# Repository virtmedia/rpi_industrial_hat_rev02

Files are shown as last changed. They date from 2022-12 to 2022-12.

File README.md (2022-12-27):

# rpi_industrial_hat_rev02
Raspberry Pi hat with industrial-style 2xDI+2xDQ+1W

## Features:
- power supply input 10-26 V with fuse protection, overvoltage protection and reverse polarity protection
- possible to set low voltage level eg. to protect 12V baterry from draining.
- 2 relays for outputs (both NO and NC contacts accesible)
- 2 optocouplers for inputs (can be used SMD or THT versions in 4-pin package)
- 3-pin connector for 1-Wire devices (eg. D18B20 thermometers)
- terminal blocks connectors
- UART conenctor
- I2C connector
- Domoticz and Home Assistant friendly

## Signals used from Raspberry Pi GPIO connector:
- GPIO04: 1-wire
- GPIO17: Relay #2
- GPIO18: Relay #1
- GPIO22: Input #1
- GPIO27: Input #2

Photo of the board (revision 01 with some small mistake, corrected in current revision):
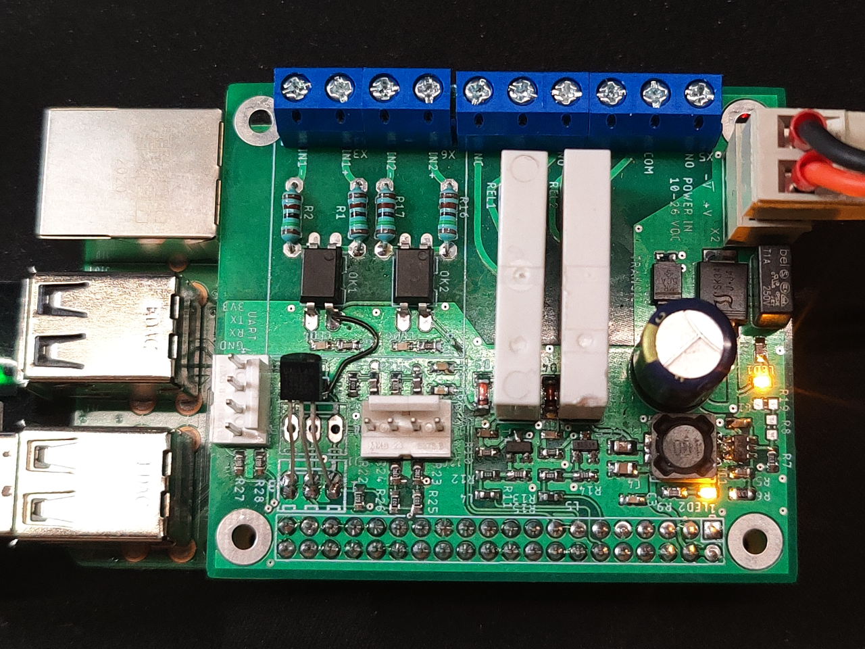
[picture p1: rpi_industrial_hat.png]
PCB photo


I've included:
- Schematic in PDF
- Board visualisation in PDF
- Gerber files in .zip ready to be send to PCB manufacturer
- Eagle files

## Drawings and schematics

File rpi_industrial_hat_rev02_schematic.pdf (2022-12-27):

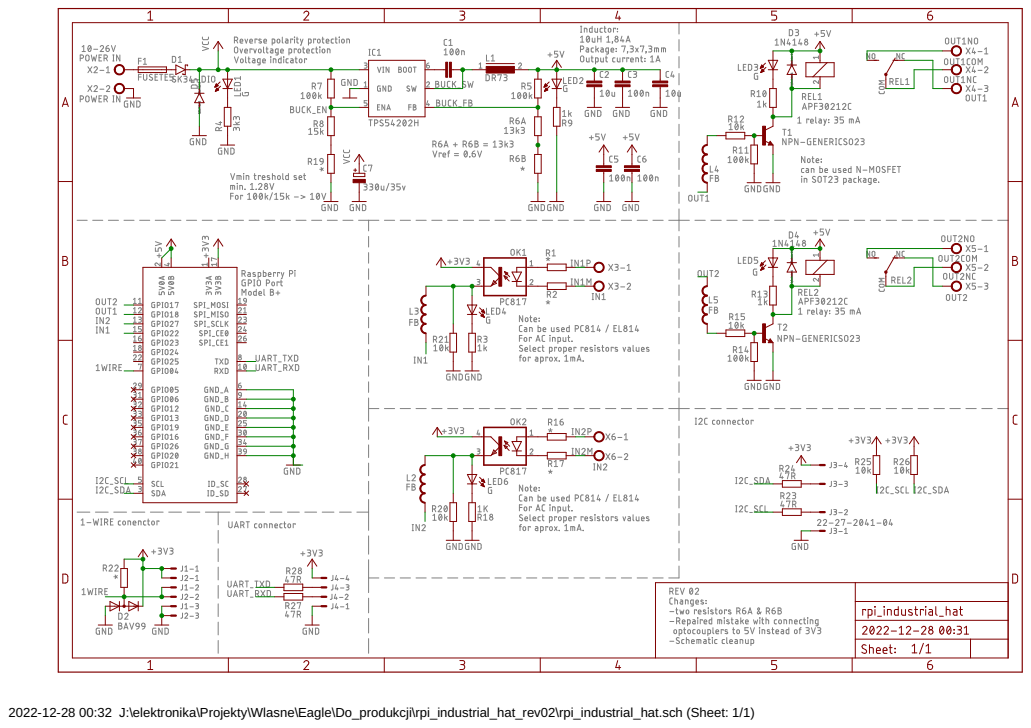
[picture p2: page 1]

2022-12-28 00:32 J:\elektronika\Projekty\Wlasne\Eagle\Do_produkcji\rpi_industrial_hat_rev02\rpi_industrial_hat.sch (Sheet: 1/1)

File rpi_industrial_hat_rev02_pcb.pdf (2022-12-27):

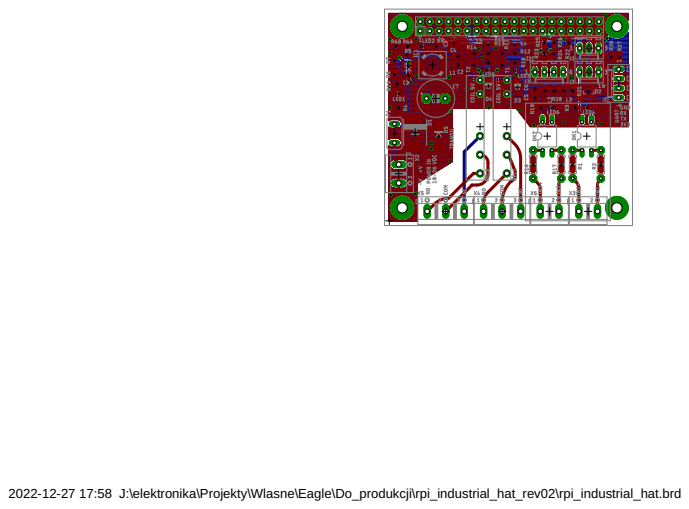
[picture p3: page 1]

2022-12-27 17:58 J:\elektronika\Projekty\Wlasne\Eagle\Do_produkcji\rpi_industrial_hat_rev02\rpi_industrial_hat.brd

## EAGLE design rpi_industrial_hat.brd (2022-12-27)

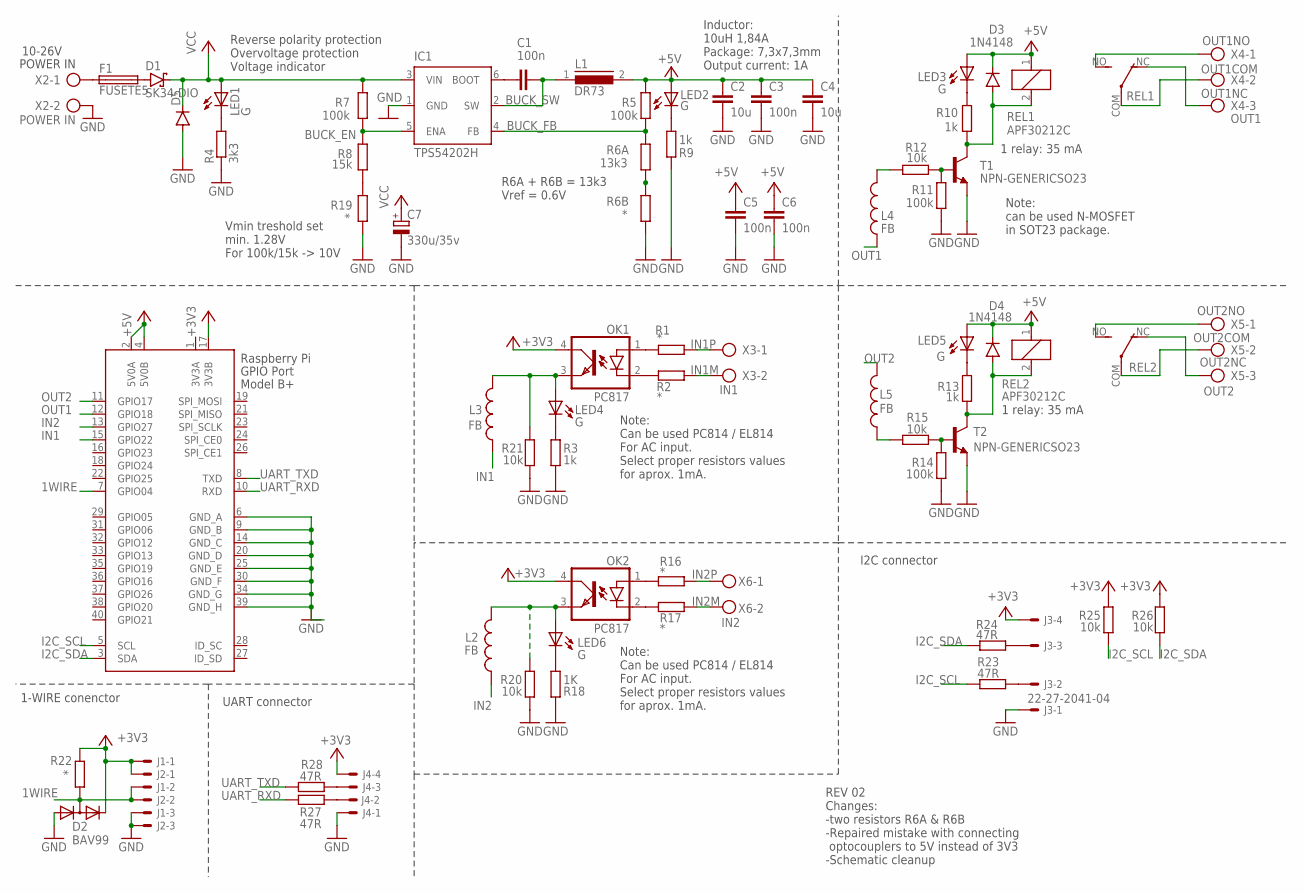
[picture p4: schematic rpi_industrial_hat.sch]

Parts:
C1, C3, C5, C6: 100n; C0603
C2, C4: 10u; C0805
C7: 330u/35v; E5-10,5
D1: SK34-DIO; SMC
D2: BAV99; SOT23
D3, D4: 1N4148; MINIMELF
D5: DIODE-DO214AA; DO214AA
F1: FUSETE5; TE5
IC1: TPS54202H; SOT23-6
J1, J2: 22-27-2031-03; 6410-03
J3, J4: 22-27-2041-04; 6410-04
L1: DR73
L2, L3, L4, L5: FB; 0603
LED1, LED2, LED3, LED4, LED5, LED6: G; CHIP-LED0603
OK1, OK2: PC817; DIL04
R1, R2, R16, R17: *; 0204/7/SMD
R3, R9, R10, R13: 1k; R0603
R4: 3k3; R0603
R5, R7, R11, R14: 100k; R0603
R6A: 13k3; R0603
R6B, R19, R22: *; R0603
R8: 15k; R0603
R12, R15, R20, R21, R25, R26: 10k; R0603
R18: 1K; R0603
R23, R24, R27, R28: 47R; R0603
REL1, REL2: APF30212C
T1, T2: NPN-GENERICSO23; SOT23
X1: RASPI_BOARD_B+#_E4P; RASPI_BOARD_B+_EDGES_4DRILL_PAD
X2: POWER IN; AK500/2
X3: IN1; AK500/2
X4: OUT1; AK500/3
X5: OUT2; AK500/3
X6: IN2; AK500/2

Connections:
1WIRE: D2.3 (K1A2), J1.2, J2.2, R22.1, X1.7 (GPIO04)
3V3A: X1.1 (3V3A)
+3V3: D2.2 (K2), J1.1, J2.1, J3.4, J4.4, OK1.4 (COL), OK2.4 (COL), R22.2, R25.1, R26.1, X1.17 (3V3B)
+5V: C2.1, C3.1, C4.1, C5.1, C6.1, D3.C, D4.C, L1.2, LED2.A, LED3.A, LED5.A, R5.2, REL1.1, REL2.1, X1.2 (5V0A), X1.4 (5V0B)
BUCK_EN: IC1.5 (ENA), R7.1, R8.2
BUCK_FB: IC1.4 (FB), R5.1, R6A.2
BUCK_SW: C1.2, IC1.2 (SW), L1.1
GND: C2.2, C3.2, C4.2, C5.2, C6.2, C7.-, D2.1 (A1), D5.A, IC1.1 (GND), J1.3, J2.3, J3.1, J4.1, R3.1, R4.1, R6B.1, R9.1, R11.1, R14.1, R18.1, R19.1, R20.1, R21.1, T1.2 (E), T2.2 (E), X1.6 (GND_A), X1.9 (GND_B), X1.14 (GND_C), X1.20 (GND_D), X1.25 (GND_E), X1.30 (GND_F), X1.34 (GND_G), X1.39 (GND_H), X2.2
I2C_SCL: R23.2, R25.2, X1.5 (SCL)
I2C_SDA: R24.2, R26.2, X1.3 (SDA)
IN1: L3.1, X1.15 (GPIO22)
IN1M: R2.1, X3.2
IN1P: R1.1, X3.1
IN1_: L3.2, LED4.A, OK1.3 (EMIT), R21.2
IN2: L2.1, X1.13 (GPIO27)
IN2M: R17.1, X6.2
IN2P: R16.1, X6.1
IN2_: L2.2, LED6.A, OK2.3 (EMIT), R20.2
unnamed: F1.1, X2.1
unnamed: D1.A, F1.2
unnamed: R8.1, R19.2
unnamed: J3.2, R23.1
unnamed: J3.3, R24.1
unnamed: OK1.1 (A), R1.2
unnamed: OK1.2 (C), R2.2
unnamed: J4.2, R27.1
unnamed: J4.3, R28.1
unnamed: LED4.C, R3.2
unnamed: C1.1, IC1.6 (BOOT)
unnamed: LED1.C, R4.2
unnamed: R6A.1, R6B.2
unnamed: D3.A, R10.1, REL1.2, T1.3 (C)
unnamed: LED2.C, R9.2
unnamed: LED3.C, R10.2
unnamed: R11.2, R12.1, T1.1 (B)
unnamed: D4.A, R13.1, REL2.2, T2.3 (C)
unnamed: LED5.C, R13.2
unnamed: R14.2, R15.1, T2.1 (B)
unnamed: OK2.1 (A), R16.2
unnamed: OK2.2 (C), R17.2
unnamed: LED6.C, R18.2
OUT1: L4.1, X1.12 (GPIO18)
OUT1COM: REL1.COM, X4.2
OUT1NC: REL1.NC (O), X4.3
OUT1NO: REL1.NO (S), X4.1
OUT1_: L4.2, R12.2
OUT2: L5.2, X1.11 (GPIO17)
OUT2COM: REL2.COM, X5.2
OUT2NC: REL2.NC (O), X5.3
OUT2NO: REL2.NO (S), X5.1
OUT2_: L5.1, R15.2
UART_RXD: R27.2, X1.10 (RXD)
UART_TXD: R28.2, X1.8 (TXD)
VCC: C7.+, D1.C, D5.C, IC1.3 (VIN), LED1.A, R7.2

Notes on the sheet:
POWER IN
Reverse polarity protection Overvoltage protection Voltage indicator
10-26V
1 relay: 35 mA
Inductor: 10uH 1,84A Package: 7,3x7,3mm Output current: 1A
R6A + R6B = 13k3 Vref = 0.6V
Vmin treshold set min. 1.28V For 100k/15k -> 10V
REV 02 Changes: -two resistors R6A & R6B -Repaired mistake with connecting optocouplers to 5V instead of 3V3 -Schematic cleanup
Note: can be used N-MOSFET in SOT23 package.
Note: Can be used PC814 / EL814 For AC input. Select proper resistors values for aprox. 1mA.
1-WIRE conenctor
UART connector
I2C connector

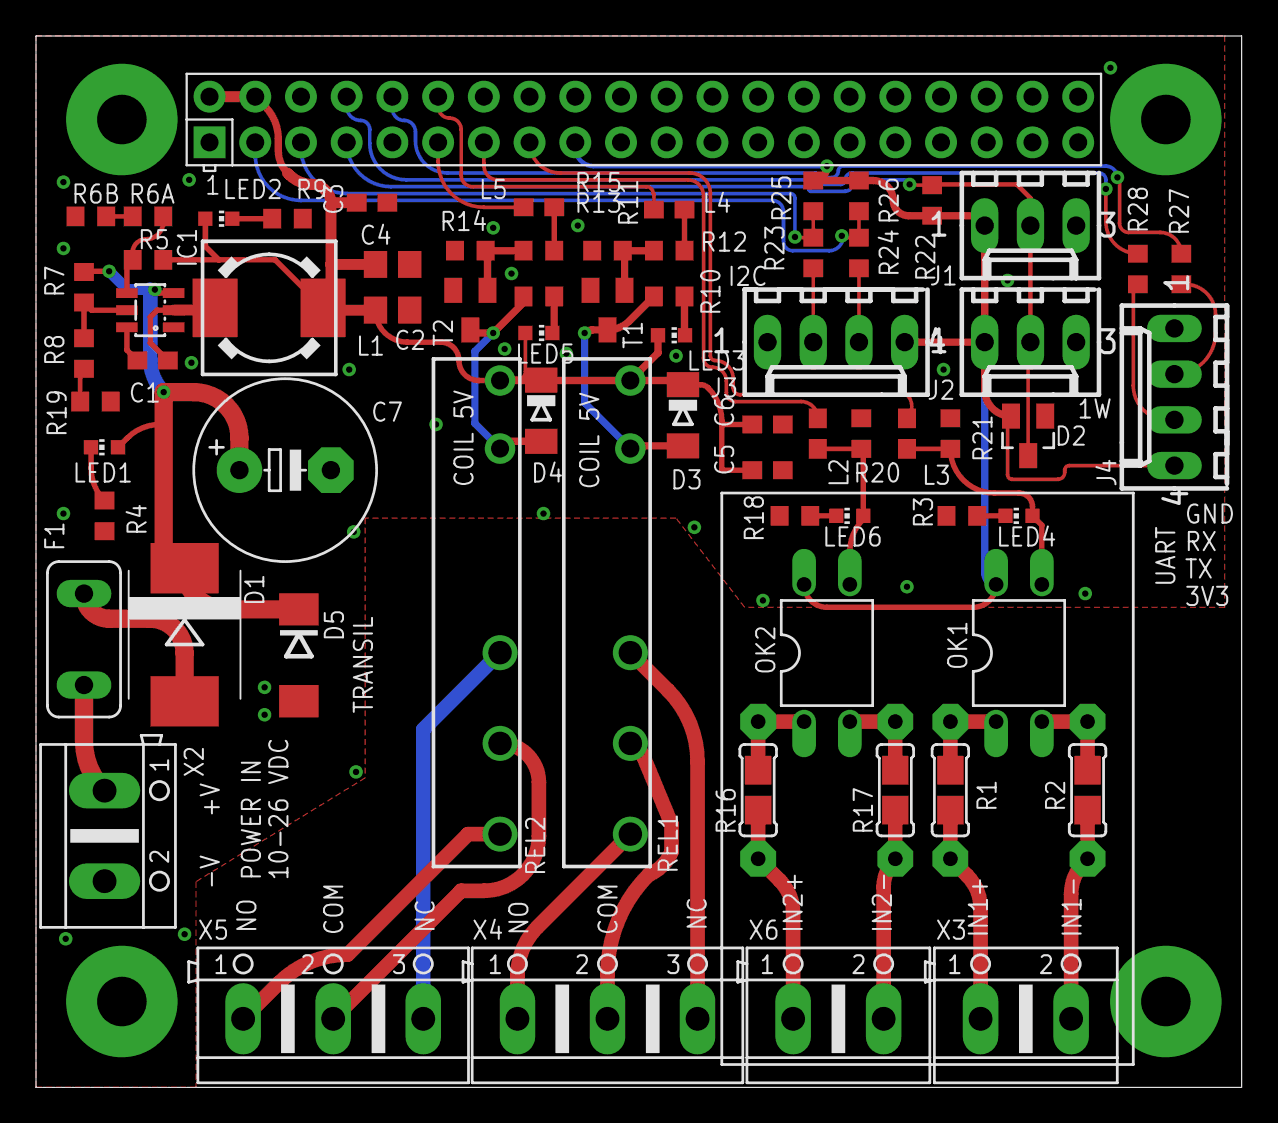
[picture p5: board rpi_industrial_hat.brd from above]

Board: 2 copper layers, 67.0 x 58.4 mm, 70 parts (0 on the bottom side), 53 nets.

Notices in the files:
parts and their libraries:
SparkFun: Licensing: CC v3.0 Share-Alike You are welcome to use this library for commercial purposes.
